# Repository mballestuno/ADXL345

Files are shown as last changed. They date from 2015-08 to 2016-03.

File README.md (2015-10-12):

# ADXL345
Using Arduino with this Digital Accelerometer integrated PCB

Files in the project

-Eagle Files
-Examples with arduino

Los acelerómetros son transductores de entrada que captan la información de una magnitud física como es la aceleración. Muy utilizados podemos tenernos incorporados en nuestros Smartphone o cuando jugamos a la WII, para medir la actividad e inactividad con nuestro cuerpo así como una posible caída .
El ADXL345 es un acelerómetro digital de 3 ejes de Analog Devices. Algunas de sus características son que tiene bajo consumo, es pequeño y tiene una alta resolución de 13 bits y se comunica a través de SPI o I2C con otros dispositivos como un microcontrolador.
En el taller construiremos la placa de expansión de Sparkfun [2] con todo lo necesario para su conexión con otros dispositivos y perfectamente serigrafiado. Puedes verla en https://www.sparkfun.com/products/9836. Nosotros lo construiremos por 2€ por lo que podrás ahorrarte un 90% eso sumado a que se aprenderá su funcionamiento y la satisfacción de haberlo realizado utilizando un horno de reflujo y desentrañando la tecnología SMD

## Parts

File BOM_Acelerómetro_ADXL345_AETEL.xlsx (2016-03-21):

BOM AETEL ADXL345
ITEM | Q. | PACKAGE Q. | PACKAGE N. | PACKAGE P. (€) | PACKAGE P. ($) | UNIT P. (€) | UNIT P.($) | TOTAL UNIT. | TOTAL PCK | UNIT LEFT | PROVIDER
Placa AETEL-Sparkfun 2C Serigrafia- Máscara soldadura 20x15mm | 1 | 40 | 1 | 0.00 € | $0.00 | 0.00 € | $0.00 | 0.00 € | 0.00 € | 20 | Manuel
ADXL345 BCCZ | 1 | 10 | 2 | 5.40 € | $5.99 | 0.54 € | $0.60 | 0.54 € | 10.79 € | 0 | http://es.aliexpress.com/store/product/5Pcs-ADXL345-ADXL345BCCZ-Inertial-sensor-3-axis-accelerometer-digital- accelerometer/511081_1695933338.html?spm=2114.04020208.3.1.St9qvK&ws_ab_test=201556_7,201527_2_71_72_73_74_75,201560_9
Capacitor 10uF Tantalo 3216 | 1 | 50 | 1 | 2.08 € | $0.00 | 0.04 € | $0.00 | 0.04 € | 2.08 € | 30 | http://es.aliexpress.com/store/product/50PCS-A-16V-10UF-106-3216-A-SMD-tantalum-capacitor/614856_2044609057.html
Capacitor 0,1uF Ceramic 0805 | 2 | 100 | 1 | 0.64 € | $0.00 | 0.01 € | $0.00 | 0.01 € | 0.64 € | 60 | http://es.aliexpress.com/store/product/Free-shipping-200pcs-0805-100NF-104-104K-0-1UF-10-X7R/511081_773492034.html
Pasta de soldadura SN63/PB37 | 1 | 1 | 1 | 3.42 € | $0.00 | 3.42 € | $0.00 | 3.42 € | 3.42 € | 0 | http://es.aliexpress.com/store/product/New-XG-50-MECHANIC-BGA-Solder-Flux-Paste-Soldering-Tin-Cream-Scraper/1179968_32346314783.html
Alternativa Pasta de soldadura sin plomo 96.5 Sn / 3 Ag / 0.5 Cu | 1 | 1 | 1 | 12.82 € | $0.00 | 12.82 € | $0.00 | 12.82 € | 12.82 € | 0 | http://es.aliexpress.com/store/product/100g-Sn42Bi58-SD-528T-low-temperature-SMT-LED-leadfree-SMT-solder-paste/1303584_32233318638.html
Aguja o jeringuillas | 1 | 1 | 1 | 3.70 € | $0.00 | 3.70 € | $0.00 | 3.70 € | 3.70 € | 0 | http://es.aliexpress.com/store/product/High-Quality-SMT-SMD-PCB-Solder-Paste-Adhesive-Glue-Liquid-Dispenser-Dispensing-Needle-50pcs/1851101_32389884513.html
TOTAL UNIT |  |  |  |  |  |  |  | 20.53 €
TOTAL ALL |  |  |  |  |  |  |  |  | 33.45 €
SELL TOTAL |  |  |  |  |  |  |  |  | 40.00 €
BENEFIT |  |  |  |  |  |  |  |  | 6.55 €
SELL UNIT | 2.0 €
UNIT number | 20
Value €/$ | 1.11

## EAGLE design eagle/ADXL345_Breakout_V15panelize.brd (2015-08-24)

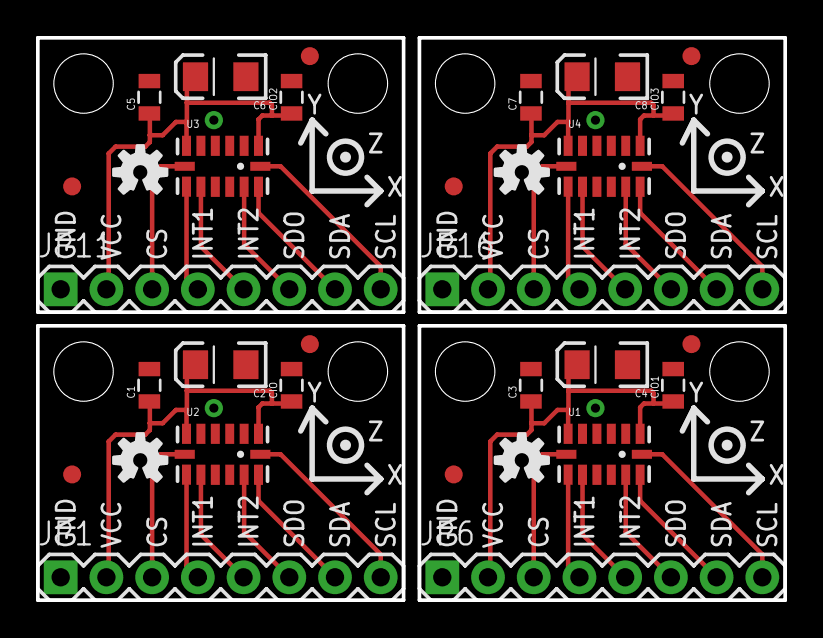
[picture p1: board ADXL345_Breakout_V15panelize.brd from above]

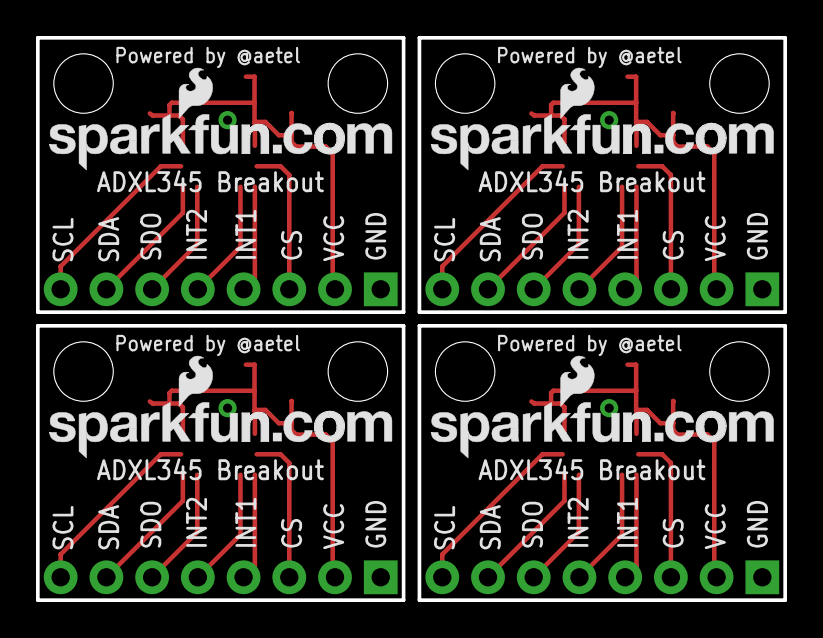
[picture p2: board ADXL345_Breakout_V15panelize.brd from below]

Board: 2 copper layers, 41.5 x 31.2 mm, 44 parts (4 on the bottom side), 32 nets.

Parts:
C1, C3, C5, C7: 0.1uF; 0805
C2, C4, C6, C8: 10uF; EIA3216
CIO, CIO1, CIO2, CIO3: 0.1uF; 0805
JP1, JP6, JP11, JP16: 1X08
JP2, JP3, JP7, JP8, JP12, JP13, JP17, JP18: STAND-OFF
JP4, JP5, JP9, JP10, JP14, JP15, JP19, JP20: FIDUCIAL1X2; FIDUCIAL-1X2
U1, U2, U3, U4: ADXL345PATRICK; LGA14_1:1_PATRICK
U$1, U$2, U$5, U$7: LOGO-SFENEW; SFE-NEW-WEBLOGO
U$3, U$4, U$6, U$8: OSHW-LOGOS; OSHW-LOGO-S

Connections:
CS: JP1.3, U2.7
CS1: JP6.3, U1.7
CS2: JP11.3, U3.7
CS3: JP16.3, U4.7
GND: C1.2, C2.C, CIO.2, JP1.1, U2.2, U2.4, U2.5
GND1: C3.2, C4.C, CIO1.2, JP6.1, U1.2, U1.4, U1.5
GND2: C5.2, C6.C, CIO2.2, JP11.1, U3.2, U3.4, U3.5
GND3: C7.2, C8.C, CIO3.2, JP16.1, U4.2, U4.4, U4.5
INT1: JP1.4, U2.8
INT2: JP1.5, U2.9
INT3: JP6.5, U1.9
INT4: JP6.4, U1.8
INT5: JP11.5, U3.9
INT6: JP11.4, U3.8
INT7: JP16.5, U4.9
INT8: JP16.4, U4.8
SCL: JP1.8, U2.14
SCL1: JP6.8, U1.14
SCL2: JP11.8, U3.14
SCL3: JP16.8, U4.14
SDA: JP1.7, U2.13
SDA1: JP6.7, U1.13
SDA2: JP11.7, U3.13
SDA3: JP16.7, U4.13
SDO: JP1.6, U2.12
SDO1: JP6.6, U1.12
SDO2: JP11.6, U3.12
SDO3: JP16.6, U4.12
VCC: C1.1, C2.A, CIO.1, JP1.2, U2.1, U2.6
VCC1: C3.1, C4.A, CIO1.1, JP6.2, U1.1, U1.6
VCC2: C5.1, C6.A, CIO2.1, JP11.2, U3.1, U3.6
VCC3: C7.1, C8.A, CIO3.1, JP16.2, U4.1, U4.6

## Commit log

2015-10-12 Creación del proyecto de Taller
    [ADXL345_Breakout_V15panelize.brd, ADXL345_Breakout_V15panelize.sch, BOM_Acelerómetro_ADXL345_AETEL.xlsx]
2016-03-21 Incluidos los archivos gerber
    [BOM_Acelerómetro_ADXL345_AETEL.xlsx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]

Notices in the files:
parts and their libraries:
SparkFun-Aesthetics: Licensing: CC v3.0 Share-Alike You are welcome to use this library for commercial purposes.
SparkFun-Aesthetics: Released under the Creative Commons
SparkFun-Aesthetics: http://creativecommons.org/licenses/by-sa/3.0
